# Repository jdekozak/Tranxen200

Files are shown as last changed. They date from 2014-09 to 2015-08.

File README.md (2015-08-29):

Tranxen200
==========

The THCRecords DrumPad code for Arduino

It contains :
* code for Arduino Mega 2560 in Tranxen200 subfolder,
* a LibreCAD file for the top metal sheet design http://librecad.org/cms/home.html
* an OpenSCAD file readable online here http://openscad.net/ or http://www.openscad.org/
* a Fritzing file for the embedded board http://fritzing.org/home/
* a UnitTests folder with a kdevelop project using cmake to debug the source code for the Arduino.

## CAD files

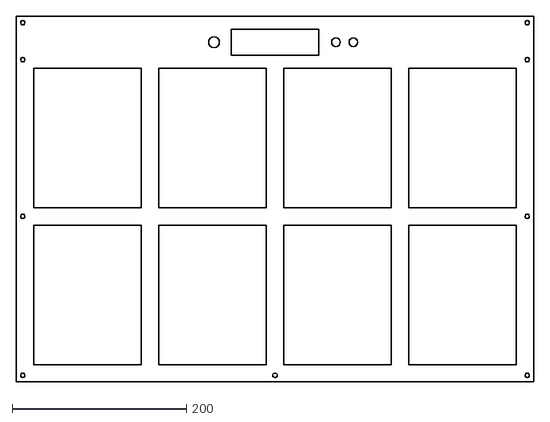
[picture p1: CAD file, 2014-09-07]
Tranxen200.dxf
594.0 x 420.0

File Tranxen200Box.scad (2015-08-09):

//globals
small_thickness = 5;
medium_thickness = 16;

A2_x = 594;
A2_y = 420;

box_height = 30;

//components
module bottom()
{
  cube([A2_x,A2_y,small_thickness]);
}

module side()
{
  cube([medium_thickness, A2_y, box_height]);
}

module front()
{
  front_x = A2_x - 2 * medium_thickness;
  cube([front_x,medium_thickness,box_height]);
}

module rear()
{
  rear_x = A2_x - 2 * medium_thickness;
  jack_holes_center_y = box_height/2;
  datasub_height = 10;
  datasub_lower_left_y=(box_height-datasub_height)/2;
  difference()
  {
                                              cube([rear_x,small_thickness,box_height]);
    translate([200.5,0,jack_holes_center_y]) rotate([270,0,0]) cylinder(h=20,r=4.5, center=true);
    translate([230.5,0,jack_holes_center_y]) rotate([270,0,0]) cylinder(h=20,r=4.5, center=true);
    translate([260.5,-5,datasub_lower_left_y])                  cube([41,20,datasub_height]);
  }
}

module inside()
{
	cube([medium_thickness, 160*2+20*2, box_height]);
}

module support()
{
  support_height = 20;
  rotate([90,90,90]) linear_extrude(height=medium_thickness) polygon([[0,0],[0,A2_y],[support_height,A2_y]]);
}

module foam()
{
  cube([123.5,160,box_height]);
}

module piezo()
{
                       cylinder(h=0.5,r=17.5);
  translate([0,0,0.5]) color("White") cylinder(h=0.5,r=12.5);
}

module plate()
{
  color("Silver") cube([123.5,160,1]);
  translate([61.25,80,,1]) piezo();
}

module pad()
{
                                      color("Grey") foam();
  translate([123.5,0,box_height+50]) rotate([0,180,0]) plate();
}

module touch()
{
  translate([20        ,20,3]) color("DimGray") cube([123.5,160,1]);
  translate([20+143.5  ,20,3]) color("DimGray") cube([123.5,160,1]);
  translate([20+143.5*2,20,3]) color("DimGray") cube([123.5,160,1]);
  translate([20+143.5*3,20,3]) color("DimGray") cube([123.5,160,1]);

  translate([20        ,200,3]) color("DimGray") cube([123.5,160,1]);
  translate([20+143.5  ,200,3]) color("DimGray") cube([123.5,160,1]);
  translate([20+143.5*2,200,3]) color("DimGray") cube([123.5,160,1]);
  translate([20+143.5*3,200,3]) color("DimGray") cube([123.5,160,1]);

  color("Black") cube([594,375,3]);
}

//box
module Tranxen200Box()
{
  translate([medium_thickness,0,small_thickness])                       color("GoldenRod") front();

  translate([medium_thickness,(A2_y-small_thickness),small_thickness])  color("Aqua") rear();
  translate([0,0,small_thickness])                                      color("GoldenRod") side();
  translate([A2_x-medium_thickness,0,small_thickness])                  color("GoldenRod") side();
                                                                        color("Aqua") bottom();

  translate([2+143.5  ,medium_thickness,small_thickness])             color("GoldenRod") inside();
  translate([2+143.5*2,medium_thickness,small_thickness])             color("GoldenRod") inside();
  translate([2+143.5*3,medium_thickness,small_thickness])             color("GoldenRod") inside();

  translate([20        ,20,small_thickness+box_height*2]) pad();
  translate([20+143.5  ,20,small_thickness+box_height*2]) pad();
  translate([20+143.5*2,20,small_thickness+box_height*2]) pad();
  translate([20+143.5*3,20,small_thickness+box_height*2]) pad();

  translate([20        ,200,small_thickness+box_height*2]) pad();
  translate([20+143.5  ,200,small_thickness+box_height*2]) pad();
  translate([20+143.5*2,200,small_thickness+box_height*2]) pad();
  translate([20+143.5*3,200,small_thickness+box_height*2]) pad();
 
  translate([0,0,small_thickness+box_height*7]) touch();

                                         color("GoldenRod") support();
  translate([A2_x-medium_thickness,0,0]) color("GoldenRod") support();
}

translate([-(A2_x/2),-(A2_y/2),-100]) Tranxen200Box();

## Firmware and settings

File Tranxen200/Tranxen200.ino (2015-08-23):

#include <MIDI.h>
MIDI_CREATE_INSTANCE(HardwareSerial, Serial2, MidiOut);

#include "PadIO.h"
#include "MidiSettingIO.h"
#include "SurfaceConfigurationIO.h"
#include "MidiSetting.h"

namespace THCRecords 
{
namespace Device
{

//Compile-time wiring
typedef PadIO<0,22> Pad0;
Pad0 pad0;
typedef PadIO<1,23> Pad1;
Pad1 pad1;
typedef PadIO<2,24> Pad2;
Pad2 pad2;
typedef PadIO<3,25> Pad3;
Pad3 pad3;
typedef PadIO<4,26> Pad4;
Pad4 pad4;
typedef PadIO<5,27> Pad5;
Pad5 pad5;
typedef PadIO<6,28> Pad6;
Pad6 pad6;
typedef PadIO<7,29> Pad7;
Pad7 pad7;
typedef PadIO<8,30> Pad8;
Pad8 pad8;
typedef PadIO<9,31> Pad9;
Pad9 pad9;
typedef SurfaceConfigurationIO<14,15,40> TheSurfaceConfiguration;
TheSurfaceConfiguration surfaceDevice;
typedef MidiSettingIO<42,44,46> TheMidiSetting;
TheMidiSetting midiDevice;

}
}

#include "Pad.h"

namespace THCRecords
{
namespace Logic
{

struct PadFactory
{
  Logic::PadInterface* create(int pad) const
  {
    Logic::PadInterface* thePad = 0;
    switch(pad) {
      case 0:
        new Logic::Pad<Device::Pad0>(Device::pad0);
        break;
      case 1:
        new Logic::Pad<Device::Pad1>(Device::pad1);
        break;
      case 2:
        new Logic::Pad<Device::Pad2>(Device::pad2);
        break;
      case 3:
        new Logic::Pad<Device::Pad3>(Device::pad3);
        break;
      case 4:
        new Logic::Pad<Device::Pad4>(Device::pad4);
        break;
      case 5:
        new Logic::Pad<Device::Pad5>(Device::pad5);
        break;
      case 6:
        new Logic::Pad<Device::Pad6>(Device::pad6);
        break;
      case 7:
        new Logic::Pad<Device::Pad7>(Device::pad7);
        break;
      case 8:
        new Logic::Pad<Device::Pad8>(Device::pad8);
        break;
      case 9:
        new Logic::Pad<Device::Pad9>(Device::pad9);
        break;  
      default:
        break;
    }
    return thePad;
  }
};

}
}

#include "Tranxen200Application.h"

THCRecords::Logic::PadFactory padFactory;
THCRecords::Tranxen200Application<10> gTranxen200(padFactory, THCRecords::Device::midiDevice, THCRecords::Device::surfaceDevice);

void setup()
{
  Serial.begin(9600);
  MidiOut.begin(1);
  gTranxen200.setup();
}

void loop()
{
  gTranxen200.loop();
}

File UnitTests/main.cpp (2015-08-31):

#include <iostream>
#include <cassert>

#include "FakeArduino.h"
#include "FakeSerial.h"
#include "FakeMidi.h"

#include "FakePadIO.h"
#include "FakeSurfaceConfigurationIO.h"
#include "FakeMidiSettingIO.h"

#include <Tranxen200/MidiSetting.h>
#include <Tranxen200/Pad.h>
namespace THCRecords
{
namespace Logic
{

struct PadFactory
{
  PadInterface* create(int pad) const
  {
    switch(pad) {
      case 0:
	return new Pad<Device::FakePadIO>(Device::padDevice0);
	break;
      case 1:
	return new Pad<Device::FakePadIO>(Device::padDevice1);
	break;
      default:
	return 0;
	break;
    }
  }
};

}
}

#include <Tranxen200/Tranxen200Application.h>

void checkLed(int pad, bool state)
{
  switch(pad) {
    case 0:
      assert(THCRecords::Device::padDevice0.led == state);
      break;
    case 1:
      assert(THCRecords::Device::padDevice1.led == state);
      break;
    default:
      break;
  }
}
void setPiezo(int pad, int value)
{
  switch(pad) {
    case 0:
      THCRecords::Device::padDevice0.piezo = value;
      break;
    case 1:
      THCRecords::Device::padDevice1.piezo = value;
      break;
    default:
      break;
  }
}

void checkMidiNote(int channel, int note, int volume)
{
  assert(MidiOut.channel == channel);
  assert(MidiOut.note == note);
  assert(MidiOut.volume == volume);
}

void onePadHit()
{
  std::cout << "#### onePadHit ####" << std::endl;
  THCRecords::Logic::PadFactory padFactory;
  THCRecords::Tranxen200Application<1> beatbox(padFactory,
					       THCRecords::Device::midiDevice,
					       THCRecords::Device::surfaceDevice);
  beatbox.setup();

  THCRecords::Device::surfaceDevice.mode = THCRecords::Tranxen200Application<1>::CONFIG;

  THCRecords::Device::surfaceDevice.relax = 2;
  THCRecords::Device::surfaceDevice.threshold = 650;
  setPiezo(0, 700);
  beatbox.loop();
  checkLed(0, true);
  setPiezo(0, 750);
  beatbox.loop();
  checkLed(0, true);
  setPiezo(0, 450);
  beatbox.loop();
  checkMidiNote(1,36,750*128/1024);
  checkLed(0, true);
  setPiezo(0,450);
  beatbox.loop();
  checkLed(0, false);

  THCRecords::Device::surfaceDevice.mode = THCRecords::Tranxen200Application<1>::PLAY;

  setPiezo(0, 600);
  beatbox.loop();
  checkLed(0, false);
  setPiezo(0, 640);
  beatbox.loop();
  checkLed(0, false);

  setPiezo(0, 700);
  beatbox.loop();
  checkLed(0, true);
  setPiezo(0, 710);
  beatbox.loop();
  checkLed(0, true);
  setPiezo(0, 750);
  beatbox.loop();
  checkLed(0, true);
  setPiezo(0, 725);
  beatbox.loop();
  checkLed(0, true);
  checkMidiNote(1,36,750*128/1024);

  setPiezo(0, 600);
  beatbox.loop();
  checkLed(0, true);

  setPiezo(0, 450);
  beatbox.loop();
  checkLed(0, false);
}

void twoPadsConfiguration()
{
  std::cout << "#### twoPadsConfiguration ####" << std::endl;
  THCRecords::Logic::PadFactory padFactory;
  THCRecords::Tranxen200Application<2> beatbox(padFactory,
					       THCRecords::Device::midiDevice,
					       THCRecords::Device::surfaceDevice);
  beatbox.setup();

  THCRecords::Device::surfaceDevice.mode = THCRecords::Tranxen200Application<1>::CONFIG;

  THCRecords::Device::surfaceDevice.relax = 3;
  THCRecords::Device::surfaceDevice.threshold = 800;
  beatbox.loop();
  checkLed(0, false);
  checkLed(1, false);

  setPiezo(1, 700);
  beatbox.loop();
  checkLed(0, false);
  checkLed(1, true);

  setPiezo(1, 750);
  beatbox.loop();
  checkLed(0, false);
  checkLed(1, true);

  setPiezo(1, 450);
  beatbox.loop();
  checkLed(0, false);
  checkMidiNote(1,37,750*128/1024);
  checkLed(1, true);

  beatbox.loop();
  checkLed(0, false);
  checkLed(1, false);

  THCRecords::Device::surfaceDevice.mode = THCRecords::Tranxen200Application<1>::PLAY;

  setPiezo(0, 500);
  setPiezo(1, 600);
  beatbox.loop();
  checkLed(0, false);
  checkLed(1, false);
  setPiezo(0, 550);
  setPiezo(1, 750);
  beatbox.loop();
  checkLed(0, false);
  checkLed(1, false);

  setPiezo(0, 601);
  setPiezo(1, 900);
  beatbox.loop();
  checkLed(0, true);
  checkLed(1, true);
  setPiezo(0, 650);
  setPiezo(1, 910);
  beatbox.loop();
  checkLed(0, true);
  checkLed(1, true);
  setPiezo(0, 625);
  setPiezo(1, 950);
  beatbox.loop();
  checkLed(0, true);
  checkLed(1, true);
  checkMidiNote(1,36,650*128/1024);
  setPiezo(0, 610);
  setPiezo(1, 925);
  beatbox.loop();
  checkLed(0, true);
  checkLed(1, true);
  checkMidiNote(1,37,950*128/1024);

  setPiezo(0, 500);
  setPiezo(1, 600);
  beatbox.loop();
  checkLed(0, true);
  checkLed(1, true);

  setPiezo(0, 450);
  setPiezo(1, 450);
  beatbox.loop();
  checkLed(0, true);
  checkLed(1, false);

  for(int relaxTime = 0; relaxTime < 22; ++relaxTime) {
    beatbox.loop();
    checkLed(0, true);
    checkLed(1, false);
  }
  setPiezo(0, 900);
  beatbox.loop();
  checkLed(0,true);
  checkLed(1, false);
  setPiezo(0, 850);
  beatbox.loop();
  checkLed(0,true);
  checkLed(1, false);
  setPiezo(0, 450);
  beatbox.loop();
  checkLed(0,true);
  checkLed(1, false);

  for(int relaxTime = 0; relaxTime < 21; ++relaxTime) {
    beatbox.loop();
    checkLed(0, true);
    checkLed(1, false);
  }

  beatbox.loop();
  checkLed(0, false);
  checkLed(1, false);
}

int main(int argc, char **argv)
{
  onePadHit();
  twoPadsConfiguration();

  return 0;
}

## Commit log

2014-08-15 Initial draft
    [Tranxen200.dxf]
2014-08-17 Add Tranxen200 box design
    [Tranxen200Box.dxf]
2014-08-21 Box design
    [Tranxen200Box.dxf]
2014-09-06 All pads must have the same size
    [Tranxen200.dxf]
2014-09-06 Add layer for measures
    [Tranxen200.dxf]
2014-09-07 Add holes diameter size
    [Tranxen200.dxf]
2014-09-13 Add measures for the box
    [Tranxen200Box.dxf]
2014-10-11 Change sizes to adapt for a 16mm thickness
    [Tranxen200Box.dxf]
2014-11-11 Move to 3D view to design the box with OpenSCAD
    [Tranxen200Box.dxf, Tranxen200Box.scad]
2014-11-16 Change the components to get an easy cut.
    [Tranxen200Box.scad]
2014-11-29 Add Foam - Pad - Piezo in an exploded 3D view
    [Tranxen200Box.scad]
2015-08-09 Tune inside separator size
    [Tranxen200Box.scad]
2015-08-26 Fritzing model for the embedded electronic board - Draft
    [Tranxen200Pad.fz]
